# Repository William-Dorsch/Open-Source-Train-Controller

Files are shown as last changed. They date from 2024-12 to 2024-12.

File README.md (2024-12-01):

# Open-Source-Train-Controller
***CURRENTLY JUST A COLLECTION OF PARTS AND CODE FOR THOSE INTERESTED***
I do not guarantee that this works, but these are the files I made it with,

***If you edit these files and improve upon them, which I highly encourage, please credit me in any re-uploads***
This is a collection of 3d print files, parts, and code to make a functional train controller for PC games.  
There are no instructions for this yet, but the parts are named well enough where I believe you can figure it out.
THIS IS A KEYBOARD EMULATOR, it does not work on the same system as a RailDriver

**REQUIRED ELECTRONICS**
Arduino Leanardo or other USB PROTOCOL CAPABLE MICROCONTROLLERS.  An Arduino Uno WILL NOT WORK
7 Cherry MX brown switches (other colors will work if you wish to have a different feel)
3 potentiometers (6 if you want the light dials) - I used DigiKeym part number  PDB12-H4301-103BF-ND for the potentiometers.  The length is important, keep that in mind.
N52 Neodynium magnets, 5mm diameter, 2mm thick
superglue, wires, and a couple breadboards
micro USB cable
Side note: throw a piece of cork roadbed under the brake lever wheel so it doesn't fall down under it's own weight

**CURRENT FUNCTIONS**
BASED ON RAIL SIM UNIVERSE FUNCTIONS< NOT TESTED WITH ANY OTHER SIMULATOR
-Horn (no quil)
-Bell
-Sand Momentary
-Sand On/Off toggle
-Door function (button press)
-conductor buzz (button press)
-Throttle - 8 notched
-Automatic brake - smooth with emergency brake at max application
-there are holes in the front plate for light dials, but I never actually built the mechanism or code for these.  Use the same potentiometers as before and have fun making it.

**PRINTING**
I think all the parts are here.  You will need to cut up these parts and slice them yourself.  Many parts are too big to actually print in one piece, but it isn't too hard to split them up in a slicer software
I used Bambu PLA and printed in the desired color.  Printer was a Bambu Lab P1S, and took the majority of a three day weekend to print all of the parts.

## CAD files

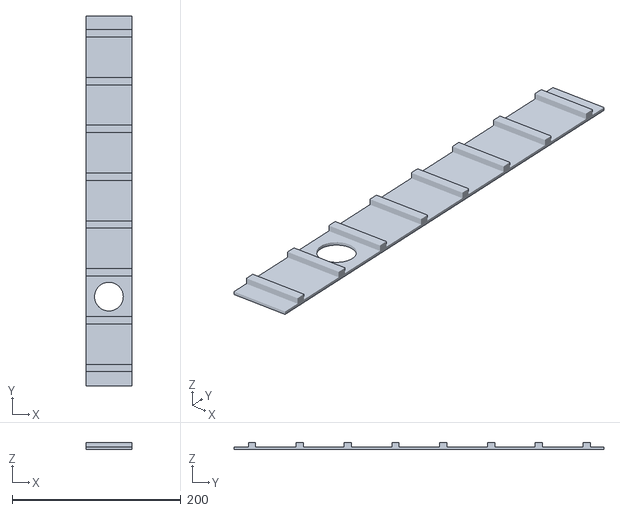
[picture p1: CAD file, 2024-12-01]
train controller parts/rearWall.stl
54.9 x 438.3 x 8.13

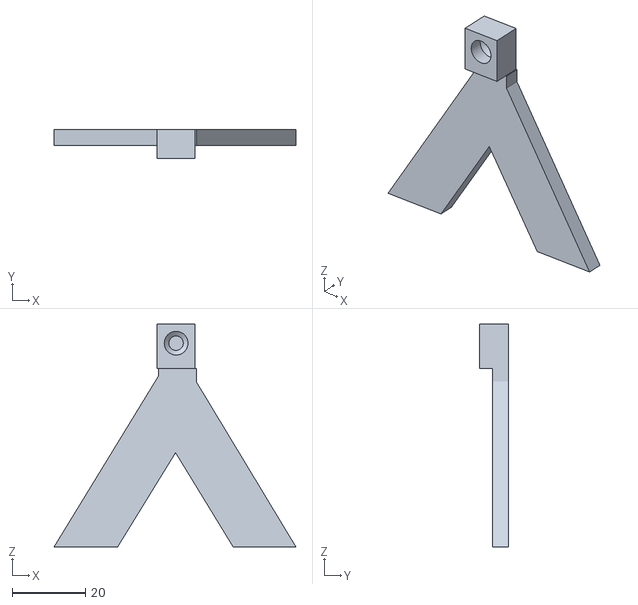
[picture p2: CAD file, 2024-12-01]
train controller parts/leverWheelPotentiometerSupprt.stl
66.0 x 8.00 x 60.8

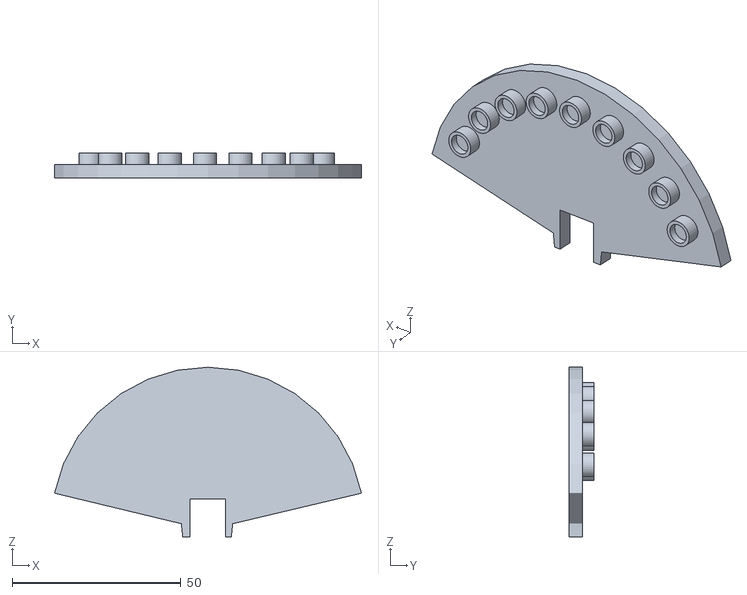
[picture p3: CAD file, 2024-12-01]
train controller parts/throttleMagnetBase.stl
90.9 x 7.53 x 50.2

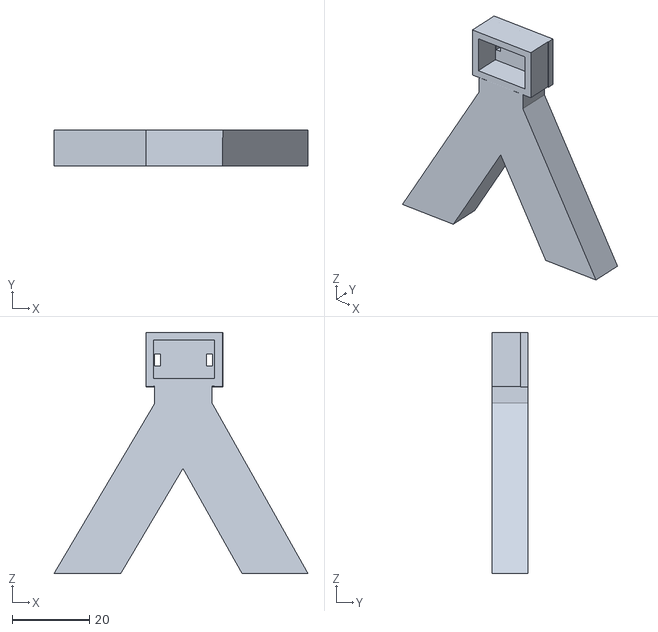
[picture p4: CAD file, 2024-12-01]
train controller parts/leverWheelPotentiometerHolder.stl
66.0 x 9.47 x 62.6

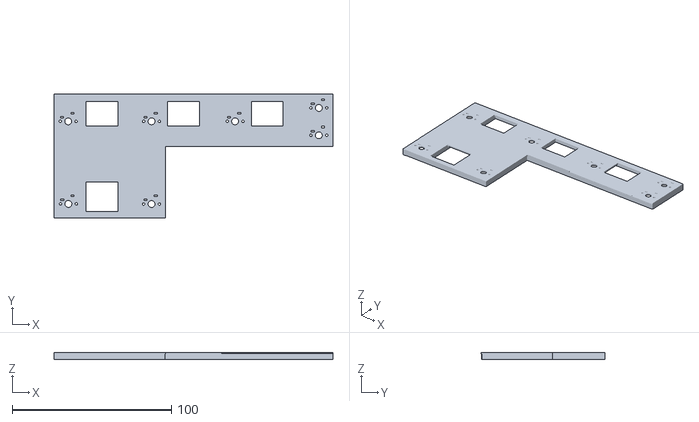
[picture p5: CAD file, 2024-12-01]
train controller parts/buttonBoard1.stl
175.0 x 77.7 x 4.56

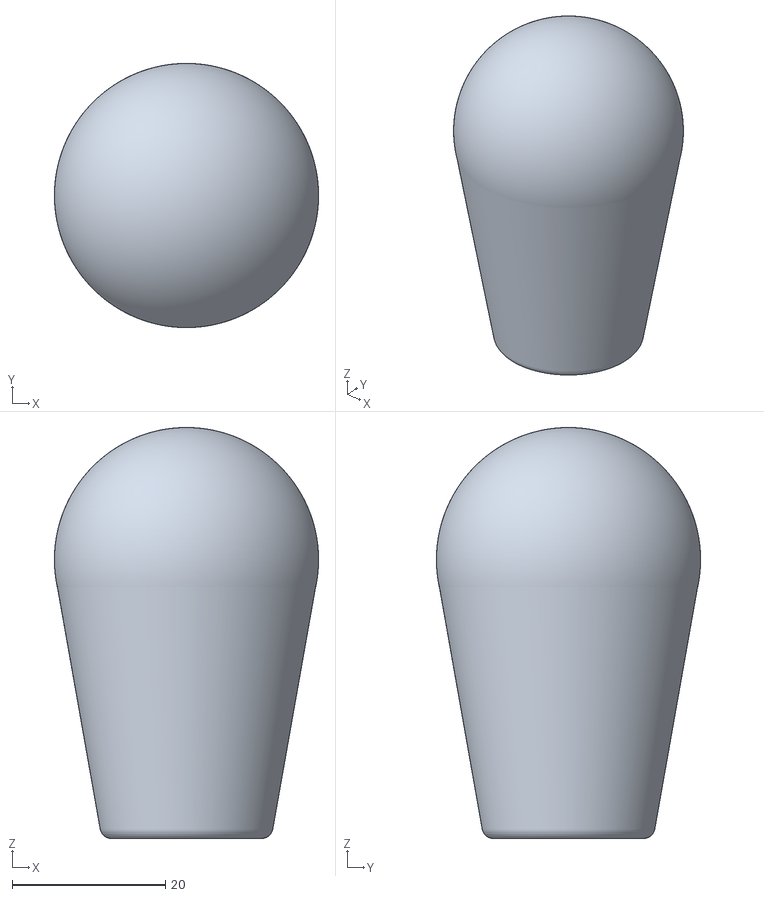
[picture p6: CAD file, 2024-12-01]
train controller parts/throttleHandle.stl
34.4 x 34.4 x 53.6

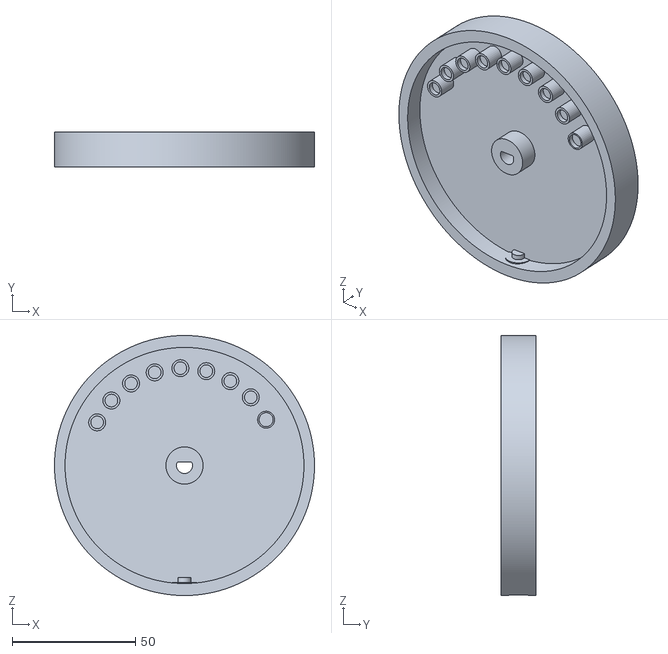
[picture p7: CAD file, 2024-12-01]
train controller parts/throttleWheel.stl
105.6 x 14.2 x 105.6

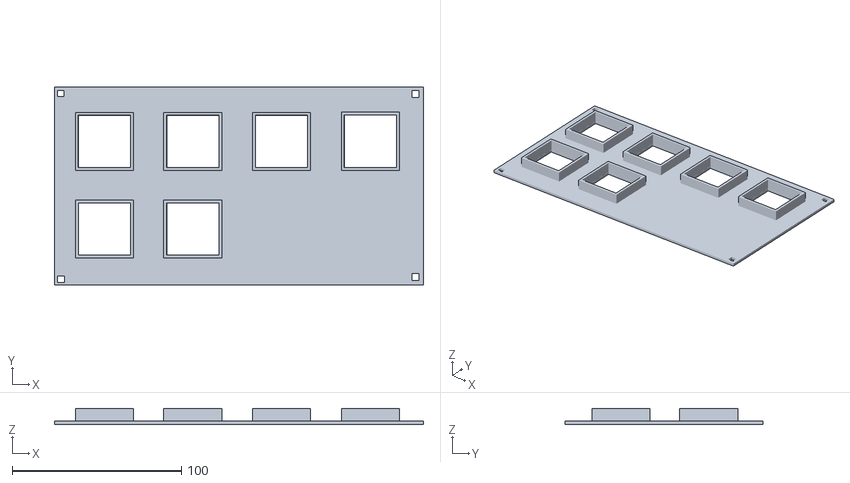
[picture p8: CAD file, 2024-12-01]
train controller parts/buttonCover.stl
218.1 x 117.3 x 9.49

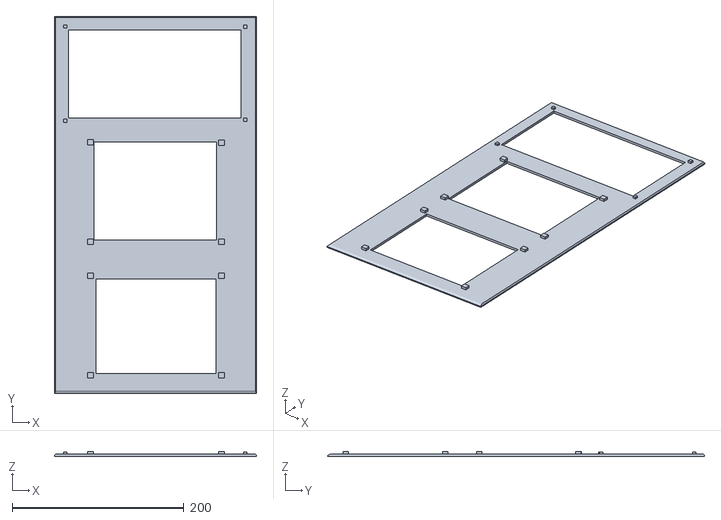
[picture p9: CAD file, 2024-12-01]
train controller parts/topPlate.stl
235.0 x 438.5 x 5.96

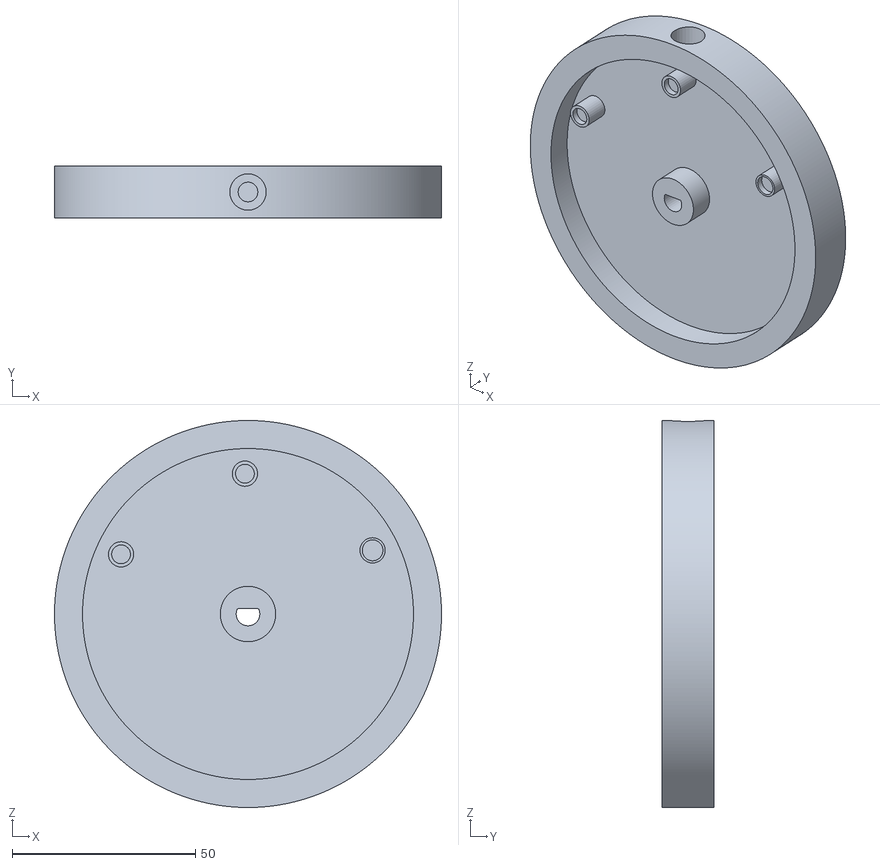
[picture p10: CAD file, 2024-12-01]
train controller parts/reverserWheel.stl
105.6 x 14.2 x 105.6

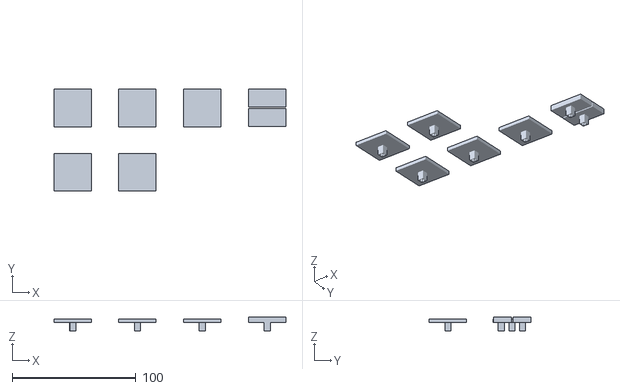
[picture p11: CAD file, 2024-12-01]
train controller parts/keycaps.stl
187.5 x 82.2 x 11.6

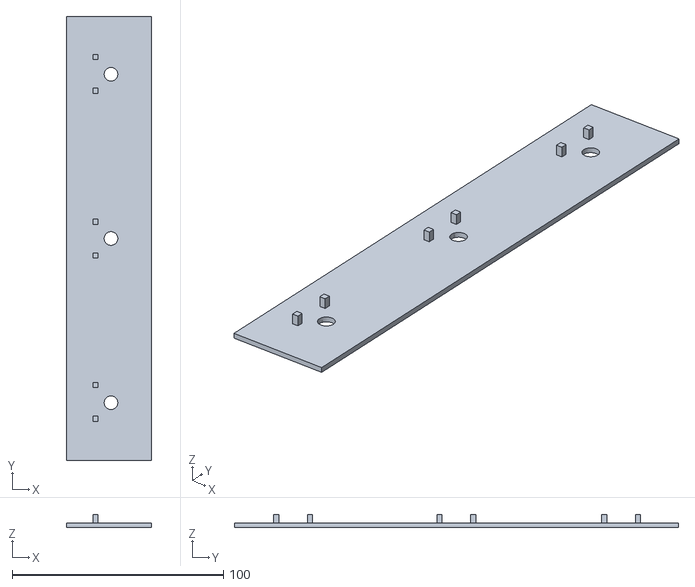
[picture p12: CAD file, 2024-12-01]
train controller parts/lightDialCoverPlate.stl
40.3 x 210.2 x 6.05

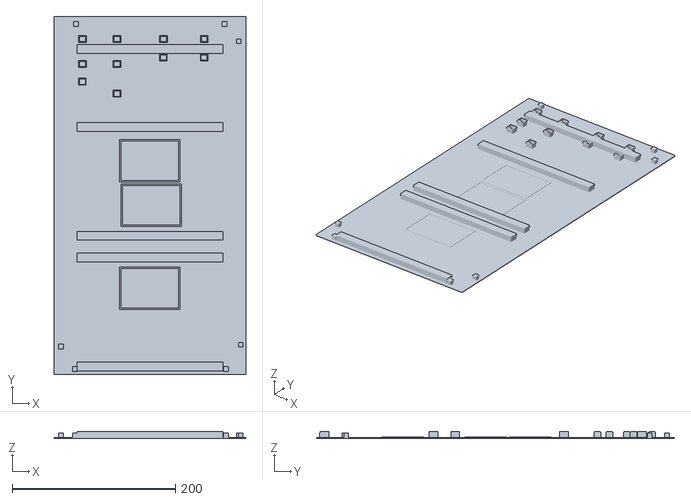
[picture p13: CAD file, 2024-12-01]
train controller parts/controllerBase.stl
235.0 x 438.4 x 8.80

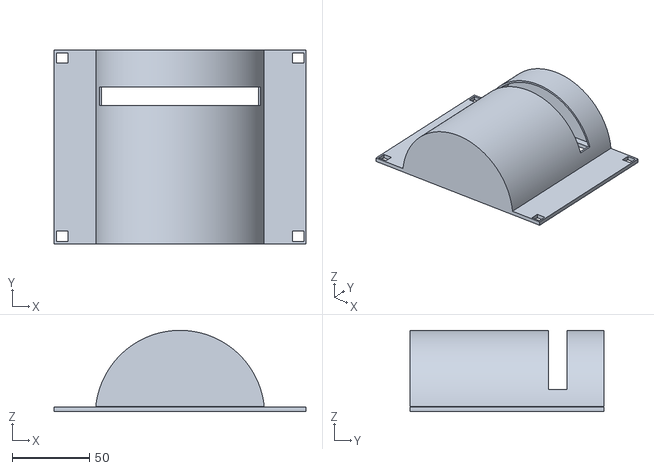
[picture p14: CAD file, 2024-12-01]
train controller parts/rightLeverCoverNO_INDEPENDENT_BRAKE.stl
162.9 x 125.5 x 52.5

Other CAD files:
train controller parts/automaticBrakeWheel.stl
train controller parts/automaticBrakeMagnetBase.stl
train controller parts/frontWall.stl
train controller parts/leverWheelBase.stl
train controller parts/automaticBrakeHandle.stl
train controller parts/buttonBoardSupports.stl
train controller parts/handleBaseRod.stl
train controller parts/leftLeverCover.stl
train controller parts/lightDial.stl
train controller parts/reverserMagnetBase.stl
train controller parts/sideWall.stl

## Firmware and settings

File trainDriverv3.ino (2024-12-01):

#include <Keyboard.h>

const int buzzer = 2; // buzzer button connects to pin 2
const int sandOn = 3; // sand on button connects to pin 3, and so on
const int sandMomentary = 4;
const int sandOff = 5;
const int door = 10;
const int bell = 7;
const int horn = 9;
const int reverser = A0;
const int throttle = A1;
const int brake = A2;
const int debounceDelay = 75; // Increased delay for debouncing
unsigned long lastBellPress = 0;

int sandState = 0;
int lastThrottlePosition = -1; // Initialize to an invalid notch to ensure first reading is registered

// Define potentiometer center values for each notch
const int notchCenters[] = {248, 305, 371, 440, 514, 577, 645, 707, 775};
const int numNotches = sizeof(notchCenters) / sizeof(notchCenters[0]);
bool eBrakeActivated = false; // Flag to check if emergency brake has been activated
// Define a tolerance range around each notch center
const int tolerance = 15;

int lastBrakePosition = -1; // Initialize to an invalid position to ensure the first reading is registered

// Define potentiometer limits
const int brakeMin = 238; // Fully released
const int brakeMax = 630; // Fully applied
const int eBrakeThreshold = 730; // Emergency brake activation threshold

void setup() {
  // put your setup code here, to run once:
  pinMode(2, INPUT_PULLUP);
  pinMode(3, INPUT_PULLUP);
  pinMode(4, INPUT_PULLUP);
  pinMode(5, INPUT_PULLUP);
  pinMode(6, INPUT_PULLUP);
  pinMode(7, INPUT_PULLUP);
  pinMode(8, INPUT_PULLUP);
  pinMode(9, INPUT_PULLUP);
  pinMode(10, INPUT_PULLUP);
  pinMode(11, INPUT_PULLUP);
  pinMode(A0, INPUT);
  pinMode(A1, INPUT);
  pinMode(A2, INPUT);
  Serial.begin(9600);
  Keyboard.begin(); // Initialize keyboard functionality
}

void loop() {
  // put your main code here, to run repeatedly:
  Serial.println(digitalRead(11));

  int potValue = analogRead(throttle); // Read potentiometer value

  // Find the current throttle position based on the closest notch center
  int throttlePosition = -1;
  for (int i = 0; i < numNotches; i++) {
    if (potValue >= notchCenters[i] - tolerance && potValue <= notchCenters[i] + tolerance) {
      throttlePosition = i;
      break;
    }
  }

  // Only send keypress if throttle position has changed
  if (throttlePosition != -1 && throttlePosition != lastThrottlePosition) {
    if (throttlePosition > lastThrottlePosition) {
      Keyboard.press('w'); // Press 'w' for throttle increase
      delay(20);
      Keyboard.release('w');
    } 
    else if (throttlePosition < lastThrottlePosition) {
      Keyboard.press('s'); // Press 's' for throttle decrease
      delay(20);
      Keyboard.release('s');
    }

    lastThrottlePosition = throttlePosition; // Update last position
  }

  delay(10); // Small delay to stabilize readings

  int BpotValue = analogRead(brake); // Read potentiometer value

  // Map potentiometer range (238-648) to brake positions (0-20)
  int brakePosition = map(BpotValue, brakeMin, brakeMax, 0, 20);
  brakePosition = constrain(brakePosition, 0, 20); // Ensure brake position stays within bounds

  // Check for emergency brake activation
  if (BpotValue >= eBrakeThreshold && !eBrakeActivated) {
    Keyboard.press(KEY_BACKSPACE); // Apply emergency brake
    delay(50); // Hold key press briefly
    Keyboard.release(KEY_BACKSPACE);
    eBrakeActivated = true; // Set the flag to prevent repeated presses
  } 
  else if (potValue < eBrakeThreshold) {
    eBrakeActivated = false; // Reset flag if below threshold
  }

  // Check if brake position has changed
  if (brakePosition != lastBrakePosition) {
    if (brakePosition > lastBrakePosition) {
      for (int i = lastBrakePosition + 1; i <= brakePosition; i++) {
        Keyboard.press('e'); // Press 'e' for each increment
        delay(20);
        Keyboard.release('e');
        delay(10); // Short delay between keystrokes
      }
    } 
    else if (brakePosition < lastBrakePosition) {
      for (int i = lastBrakePosition - 1; i >= brakePosition; i--) {
        Keyboard.press('q'); // Press 'q' for each decrement
        delay(20);
        Keyboard.release('q');
        delay(10); // Short delay between keystrokes
      }
    }

    lastBrakePosition = brakePosition; // Update last brake position
  }


  delay(10); // Small delay to stabilize readings

  //horn function
  if (digitalRead(horn) == LOW){
    Keyboard.press('n');
  } else if (digitalRead(horn) == HIGH){
    Keyboard.release('n');
  }

  //bell function
  if (digitalRead(bell) == LOW) {
        if (millis() - lastBellPress > debounceDelay) {
            Keyboard.press('b');
            lastBellPress = millis();
        }
    } else {
        Keyboard.release('b');
    }

  //sand button logic
  if (digitalRead(sandOn) == LOW){
    digitalWrite(2, HIGH);
    sandState = 1;
  } else if (digitalRead(sandOff) == LOW){
    digitalWrite(2, LOW);
    sandState = 0;
  } 

  if (sandState == 1){
    Keyboard.press(KEY_LEFT_SHIFT);
  } else if (sandState == 0){
    Keyboard.release(KEY_LEFT_SHIFT);
  }

  if (sandState == 0){
    if (digitalRead(sandMomentary) == LOW){
    Keyboard.press(KEY_LEFT_SHIFT);
    } else if (digitalRead(sandMomentary) == HIGH){
    Keyboard.release(KEY_LEFT_SHIFT);
    }
  }

  //door function
  if (digitalRead(door) == LOW){
    Keyboard.press('t');
  } else if (digitalRead(door) == HIGH){
    Keyboard.release('t');
  }

  


}
